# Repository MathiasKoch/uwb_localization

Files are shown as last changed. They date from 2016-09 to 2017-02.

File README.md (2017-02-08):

# Ultrawide band based localization system

First off, a comprehensive wiki on this sytem can be found at: [RSE-WIKI - 3D localization](http://rsewiki.elektro.dtu.dk/index.php/3D_localization)

The entire system is build to be easily ported to new hardware platforms, with minimum configuration.

The general folder structure is describe below, with the important hardware specific files highlighted and described.

| Folder | Contains |
| --- | --- |
| Drivers/ | Peripheral libraries, IMU drivers, DWM drivers, etc. |
| Inc/ | Include files (.h) |
| Inc/$(CPU)/ | Processor/device specific include files |
| Inc/hal.h | Hardware abstraction configuration file (Add new devices here first) |
| Linkers/ | Linker files for GCC (Processor specific) |
| MATLAB/ | MATLAB simulation scripts and design files |
| Middlewares/ | Middleware libraries (eg. USB middlewares) |
| PCB/ | DipTrace files for the PCB design |
| Related papers/ | Papers I have found relevant for the project |
| Scripts/ | Various helper scripts (eg. Python scripts for DFU management) |
| Src/ | All of the source files (.c/.cpp) |
| Src/$(CPU)/ | Processor/device specific source files |
| Src/periph/ | Peripheral setup source files (i2c, spi, tim, dma, etc.) |

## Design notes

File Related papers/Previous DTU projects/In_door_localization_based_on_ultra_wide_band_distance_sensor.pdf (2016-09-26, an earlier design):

## In-door Localization based on Ultra Wide Band Distance Sensor

Mathias Koch, s123950
Nicolai Sahl-Tjørnholm, s123860

DTU, 11. December 2015

Mathias Koch | Nicolai Sahl-Tjørnholm

## Abstract

To navigate an autonomous robot safely in its surroundings, the position of it must be known to some extent. One way of doing this is by having an external system capable of tracking the device of interest.
In this report a robust positioning system is introduced and tested. It consists of four anchors and one tag, and the position of the tag is estimated by trilateration of the distances from anchors to the tag. The final system is using a non-linear least squares algorithm to perform the trilateration.
Different test scenarios are set up and the results are compared. Tracking of a moving tag was showing very precise estimations, but with the same errors for every repetition of the same test. Tests with a non-moving tag showed estimation errors of ±5 cm.

## Contents

1 Introduction | 3
2 System Overview | 4
3 Position Estimation | 5
4 Results | 9
5 Conclusion | 13
6 Future Works | 13
7 References | 14
8 Appendix | 15

## 1 Introduction

To navigate a device through an environment it is crucial to know its position compared to the surroundings. It does not become less important when dealing with autonomous devices like a driving robot or an autonomous drone. To deal with this problem, a variety of sensors can be placed on-board the devices, to estimate its current position compared to its starting position, by for instance sensing acceleration in different directions. The problem with these techniques is that there will always occur some sort of drift in the measurements, meaning that as time goes on the error in the estimated position will increase. To correct this drifting of measurements, a system that estimates the device position based on distances to other devices, placed in the surroundings, can be used. These estimates can be fused with on-board sensors, to combine the best of both worlds.

Today the most commonly used and well known system of this type, is the Global Positioning System (GPS). It computes distances between satellites with known positions, to a GPS-device on earth and by utilizing geometry, it estimates the position of the GPS-device. This method has some quite unfortunate disadvantages such as low accuracy and extremely poor performance when used indoors. When it comes to navigation of robots, it is often required to have a high accuracy and it should be able to be used indoors.

Alternatives that are actually made for indoor positioning purposes is local positioning systems. These types of systems work somewhat like the GPS. Distances from anchors with known positions, are measured to a tag and a relative position is estimated. The way the distances are measured in these systems are by either by loss in signal strength or delay from transmission time till reception of a signal. The signal strength method is enough to estimate which room a device is in, but not much more than that. The signal delay method is more precise, but it is influenced by noise sources that uses the same RF bands as the transmitted signals. To overcome this issue, devices with Ultra Wide Band (UWB) transceivers has been developed. It is this technology that is explained throughout this report and used to obtain a high precision positioning system.

## 2 System Overview

The system consists of several devices that communicates and performs distance measurements to each other with UWB transceivers. The transceivers used are DW1000, a low power, single chip CMOS radio transceiver IC produced by decaWave. They span 6 RF bands from 3.5 GHz to 6.5 GHz and support data rates of 110 kbps, 850 kbps and 6.8 Mbps[1]. Due to the wide span on the RF bands, the performance of the transceivers are not affected by noise, in the same way a narrow banded system would be. This is due to the interferences often coming from narrow banded systems, like bluetooth or WiFi, thus having lower impact on a wide banded system. The manufacturer states that the operating range of the system may vary from 60 m line-of-sight (LOS) at 6.8 Mbps data rate to 250 m at the 110 kbps data rate and the accuracy is stated to be +/- 10 cm.
For this report a setup was made from four anchor nodes and one tag. It is possible, and recommended, to expand the system so that it consists of more anchors, since this will result in higher precision tracking and be more fault tolerant.

### 2.1 Distance measurements

In order to do distance estimation, a ranging algorithm based on time of flight is being used. This means that every communication package between nodes are precisely timestamped at time of transmission and again at time of reception, in order to calculate the propagation time. As the speed of light is constant, the distance between the transmitter and the receiver can be calculated as a direct scalar of the propagation time. In theory this alone should give a very accurate distance measurement, but this is not the case in reality. This is due to the fact that there is a lot of different delays in both the transmitting unit and the receiving unit, delays that are not always constant. The delays could depend on things like package size, processor type, electronics layout, transmission data rate and so forth. Furthermore the clocks of the two nodes has to be synchronized to perfection in order to have comparable timestamps, which is not possible as the crystals has some drift.

The solution to some of these issues, is to use what is called a two-way ranging scheme, allowing the system to compensate for some of the drift in the clock synchronization and some of the variable delays in the system. In a basic single-sided two-way ranging scheme you measure the time it takes for a message to propagate from device A to device B and reverse, subtracting the processing time on device B and dividing by two to get the average propagation time. In this case, an extension of the normal single-sided two-way ranging scheme is used called Double-sided Two-way ranging. The extension of the basic single-sided two-way ranging, means that instead of measuring the propagation time from one node to the other and back again, the process is repeated in reverse, meaning that the round-trip of device A to device B and back again is measured, and the round-trip time of device B to device A and back again is also measured. This makes it possible to compensate, in case of any difference in the processing time, internal delays etc. between the two devices. The process can be optimized, by using the reply from the first round-trip, as an initiator for the second round-trip, as seen in figure 1. It is however worth noting that even though this ranging scheme allows a good range estimate in just three packages, the last package ends up at the opposite device, of who initiated the

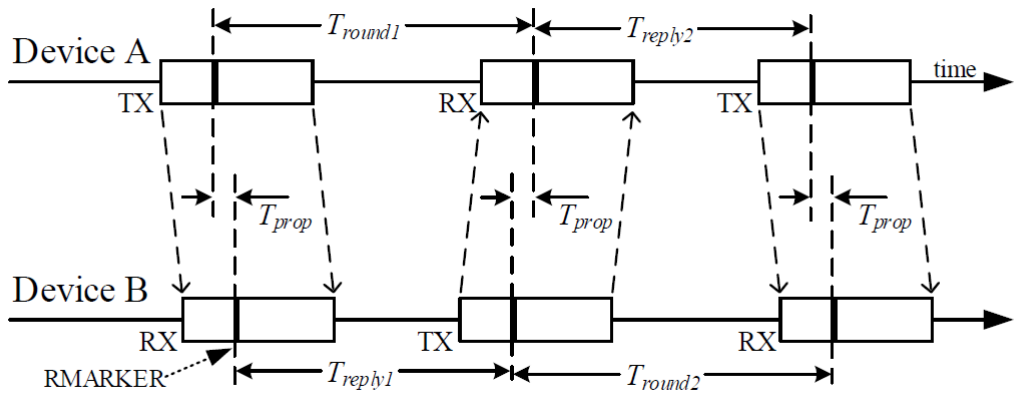
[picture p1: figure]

Figur 1: Double-sided Two-way ranging, using the reply of the first round-trip as initiator for the second round-trip.

ranging. This means that a fourth package is required to report the last Tround2 back to the initiator for distance calculation.

The resultant time-of-flight estimate Tprop can now be calculated as

Tˆ
prop =

Tround1Tround2 − Treply1Treply2

Tround1 + Tround2 + Treply1 + Treply2

(1)

And the distance can be calculated as

ri = TpropC | (2)

Where C is the speed of light, 3 · 10⁸ m/s.

## 3 Position Estimation

The problem of estimating the position of an object with unknown position, based on distance measurements between the object and multiple reference points, with known positions, are known as trilateration [2]. In theory trilateration is as simple, as solving a system of equations in the form of
(pi − p0)

T
(pi − p0) = r

2
i

(3)

where p0 denotes the position estimate of the object, pi the known position of the i’th reference point and ri the measured distance between the object and the i’th reference point. When structuring the trilateration problem in this way, equation (3) is equivalent to the equation of a sphere, with center point in pi and radius of ri
. The solution to a system like this, is essentially equivalent to finding the intersection point of the N spheres contained in the system, this intersection point will be the unknown position, p0.

This can be solved in a number of ways, ranging in complexity from simple hyperbolic interpolation and least squared methods to Extended Kalman filters and Particle filters. In this report we have chosen to focus on the least squares methods.

### 3.1 Linear Least Squares

The problem of estimating a position in 3 dimensions, from N distance measurements to known positions, can be solved as a least squares optimization problem. To do this the problem can be simplified into a linear system of N equations with 3 unknown variables in the form Ax = b, with

A =

P2,x − P1,x | P2,y − P1,y | P2,z − P1,z
P3,x − P1,x | P3,y − P1,y | P3,z − P1,z
Pn,x − P1,x | Pn,y − P1,y | Pn,z − P1,z

, x =

P0,x − P1,x

P0,y − P1,y

P0,z − P1,z

- , b =

b21

b31

bn1

(4)

where

(P0,x −P1,x)(Pn,x −P1,x) + (P0,y −P1,y)(Pn,y −P1,y) + (P0,z −P1,z)(Pn,z −P1,z) = bn1 (5)

1
2

[r

2
1 − r

2
n + d

2
n1

] = bn1

and dij being the distance between the i’th and the j’th node, given as

dij =

q
(Pi,x − Pj,x)

2 + (Pi,y − Pj,y)

2 + (Pi,z − Pj,z)

2 | (6)

The full derivation of these equation can be found in Appendix A.
With this given, a new problem arises, as the distance measurements contains noise and is therefore only distance approximations with some uncertainty. This is where the least squares approximation comes into play, as this uncertainty essentially means, that we are searching for a solution x, such that Ax ≈ b. By minimizing the sum of the squares of the residuals,

S = r

T
r = (b − Ax)

T
(b − Ax), | (7)

the following equation can be obtained [3]

AT Ax = ATb | (8)

From here, there are several possible methods to solve this equation, based on how AT A is conditioned. In this report we will only investigate the case where AT A is non-singular and well-conditioned, leading to the simple solution given in equation (9).

x = (AT A)

−1ATb | (9)

Now the position estimate of the robot p0, can be found as

p0 = x + p1 | (10)

In the cases where AT A is either singular or poorly conditioned, there is as mentioned before, still ways to solve the linear system of equations. These involves either normalized orthogonal decomposition or singular value decomposition. These cases will however not be investigated in this report, as the results of the best case, where AT A is non-singular and well-conditioned deemed unsatisfactory and neither of the two extended methods will increase the accuracy. The unsatisfactory solution, is due to the nonlinear nature of equation (3) and the errors existing in both the fixed reference positions, pi and the measurements, ri

, making it impossible for the linear least squares method to approximate the position with higher accuracy.

### 3.2 Nonlinear Least Squares

To overcome some of the issues with the linear least squares implementation, an algorithm based on a nonlinear least squares formulation is implemented instead. The efficient least squares trilateration algorithm [4]. The Efficient Least Squares Trilateration Algorithm for Mobile Robot Localization, used has the major advantage, that it is built solely on simple algebraic matrix instructions, meaning no matrix inversion is involved in the algorithm. This makes for an extremely robust algorithm, in the sense that it can handle singular matrices e.g. in the case of all anchors being positioned in the same single plane. Furthermore it means that the algorithm is extremely fast to process, which is an important factor, as the processing power might be very limited in real life applications.
Essentially the algorithm proposes a way to obtain the optimal position estimate of the robot, as an minimization problem in the form:

p0,opt = argmin
p0
S(p0) | (11)

Where
S(p0) = X

N

i=1

[(pi − p0)

T
(pi − p0) − r

2
]

2
(12)

With p0 denoting the estimated position of the robot, pi the position of the i’th reference point, N the number of reference points used and ri the measured distance between p0 and pi .

Using a least squares algorithm, we relieve ourselves from the constraint that is usually asso-ciated with equation systems with noise present, being that as soon as more equations are available than unknown variables, the system generally does not have one exact solution. This means that courtesy of using least squares approximations we are not limited to the case where N = 3, but this solution can be used in the general case where N ≥ 3, N ∈ N.

It has been chosen to include only the final equations required to calculate the position estimate in the report, the full derivation of said equations can be found in Appendix B.

The algorithm can be described in 7 steps:

1. Calculate a,B,c,f,f ’,H,H’,Q and U, from equations (13) - (20).
2. Calculate q

T q, from equation (21).

3. Calculate q3, from equation (24).
4. Calculate q1 and q2, from equation (25).
5. Calculate p0, from equation (26).
6. Choose one of the two candidates of p0.
7. Return p0.

a =

1
N

X

N

i=1

(pip

T
i pi − r

2
i pi), | a ∈ M3x1(R) | (13)

B =

1
N

X

N

i=1

[−2pip

T
i − (p

T
i pi)I + r

2
i
I] , | B ∈ M3x3(R) | (14)

c =

1
N

X

N

i=1

pi

, | c ∈ M3x1(R) | (15)

f = a + Bc + 2ccT
c , | f ∈ M3x1(R) | (16)

f

0 = [f1 − f3, f2 − f3]
T
, | f
| 0 ∈ M2x1(R) | (17)

H = −

2
N

X

N

i=1

pip

T

i + 2ccT
, | H ∈ M3x3(R) | (18)
H⁰ = [H1 − H3, | H2 − H3]
T
, | H⁰ ∈ M2x3(R) | (19)

The two matrices Q and U, can be obtained by orthogonal decomposition [5] of H’, with the result given by the relation
H⁰ = QU | (20)

Where Q is a 2x2 orthogonal matrix, and U is a 2x3 upper diagonal matrix.

q

T q =

1
N

X

N

i=1

(r

2
i − p

T
i pi) + c

T
c , | q
tq ∈ R | (21)

In the following, ukj references the element in the k’th row and the j’th column of U, vk references the k’th element of the vector QT
f

0 and qk references the k’th element of q. To make matters a little easier to read, we introduce 2 helping variables here given as

g1 =

u12v2

u11u22

−

v1

u11
(22)

g2 =

u12u23

u11u22

−

u13

u11
(23)

q3 can now be found as

q3 =

±1

g

2
2 +
u23

u22 2
+ 1
g1g2 +
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
u22 2
− g

2
1 + 2g1g2
v2

u22

u23

u22
(24)

− g

2/2
v2

u22 2
+ q

T qg

2
2 −
v2

u22 2
+ q

T q

u23

u22 2
+ q

T q

1/2

This will give rise to two solutions, due to the ±1, with only one of the two candidates resulting in the true p0. The true q can be chosen based on a number of criterion’s based on the application, e.g. it could be known that the true p0 is always on a specific side of the base plane, or that the current p0 cannot move far from the previous estimate of p0.

Now that we know the height of the p0 point, we can substitute into the two equations

q1 = g1 + g2q3 | q2 =
−

v2

u22

−

u23

u22
q3 | (25)

Lastly the estimated position can be obtained by

p0 = q + c | (26)

## 4 Results

During the project various techniques and methods have been tested, in order to achieve the best possible position estimate. This includes multiple time-of-flight range calculation schemes, different methods for solving the trilateration problem and eventually simple hardware alterations to reduce reflections.

Looking at just a single series of distance measurements, before processing the data will give the best overall assessment of what the system might be capable of, assuming the data is processed right. Such a measurement series can be seen in figure 2, together with the mean value of the series shown and ±3σ highlighted as a confidentiality interval. As it can be seen from the figure, nearly all of the measurements are within ±5 cm, way better than the specified ±10 cm from the manufacturer. These results are consistent across all of the tests conducted with non-moving nodes. The obtained precision is consistent with moving modes as well, as long as the nodes are in line of sight and does not come to close to the other tag, as they seem to require a minimum distance between each other of 10-15 cm.
With raw distance measurements within ±5 cm of each other, the system should be capable of delivering quite accurate three dimensional position estimates. There is however a couple of other things in play, when calculating position from distance measurements. First of all there is an overdetermined system of equations to be solved, as soon as more than three reference points are introduced and with the addition of measurement noise, these are generally prone to have no real solution. This means that the best position estimate obtainable is the position that makes for the least error, making it an optimization problem. This has been solved by the least squares method, leading to accurate position estimates in the cases where there is line of sight between the tag and all the anchors, there is no motion of any of the nodes and the nodes are oriented and positioned in a way that minimizes the reflection impact on the measurements.

Measurements of distance between two node laying still

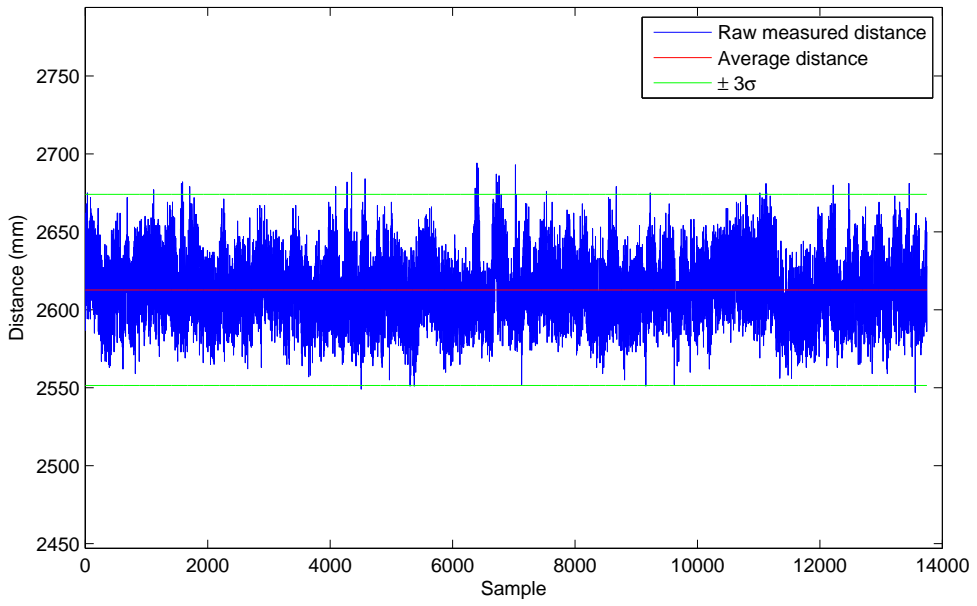
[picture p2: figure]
Sample; Distance (mm); Raw measured distance Average distance ± 3σ

Figur 2: Measurement series of distance between two nodes laying still.

In figure 3, the X and Y position of a small mobile robot, equipped with a tag and driving a preprogrammed route, can be seen before orienting and positioning the nodes to minimize reflection impact. It can be seen how the measurements are somewhat along the expected route, but with a lot of jitter, offset and unexplainable behaviour. As it turns out, this behaviour is explainable though, as it is cause by wrong distance measurements as a consequence of the reflections from walls containing higher power at reception than the direct route. This can be explained by looking at the antenna profile of the modules, as this antenna has so called dead-spots where the reception gains are extremely low. This means that in the case where the direct line of sight route hits a dead-spot and the reflections hits a non-dead-spot on the antenna, the reflections will seem like the superior signal to the system.

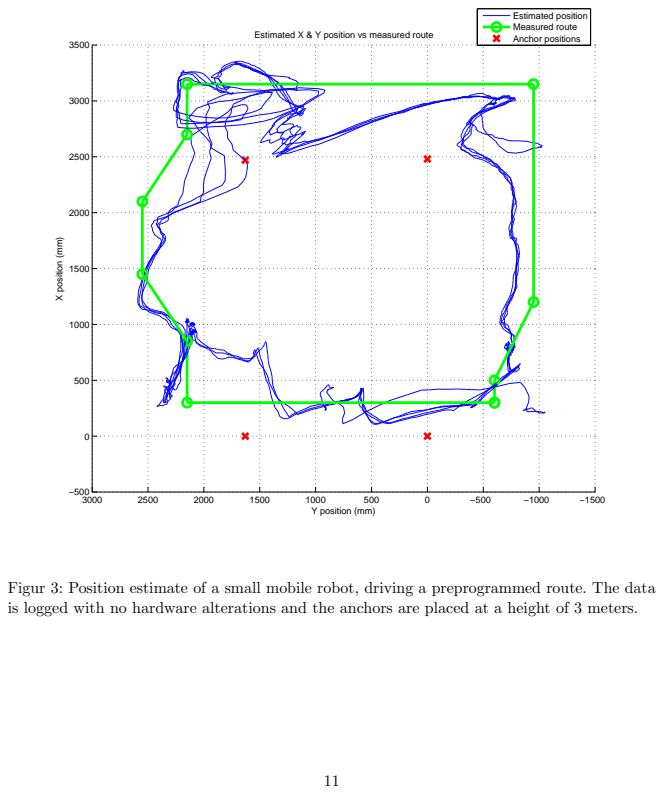
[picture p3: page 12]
Y position (mm); X position (mm); Estimated position Measured route Anchor positions

Estimated X & Y position vs measured route

Figur 3: Position estimate of a small mobile robot, driving a preprogrammed route. The data
is logged with no hardware alterations and the anchors are placed at a height of 3 meters.

By correcting for these antenna dead-spots as much as possible, it was possible to obtain much better results. In figure 4, the same small mobile robot, driving the same preprogrammed route can be seen, but this time the results are much better. The estimated route is still not the correct route, but there is a much better coherence between the estimated and true route.

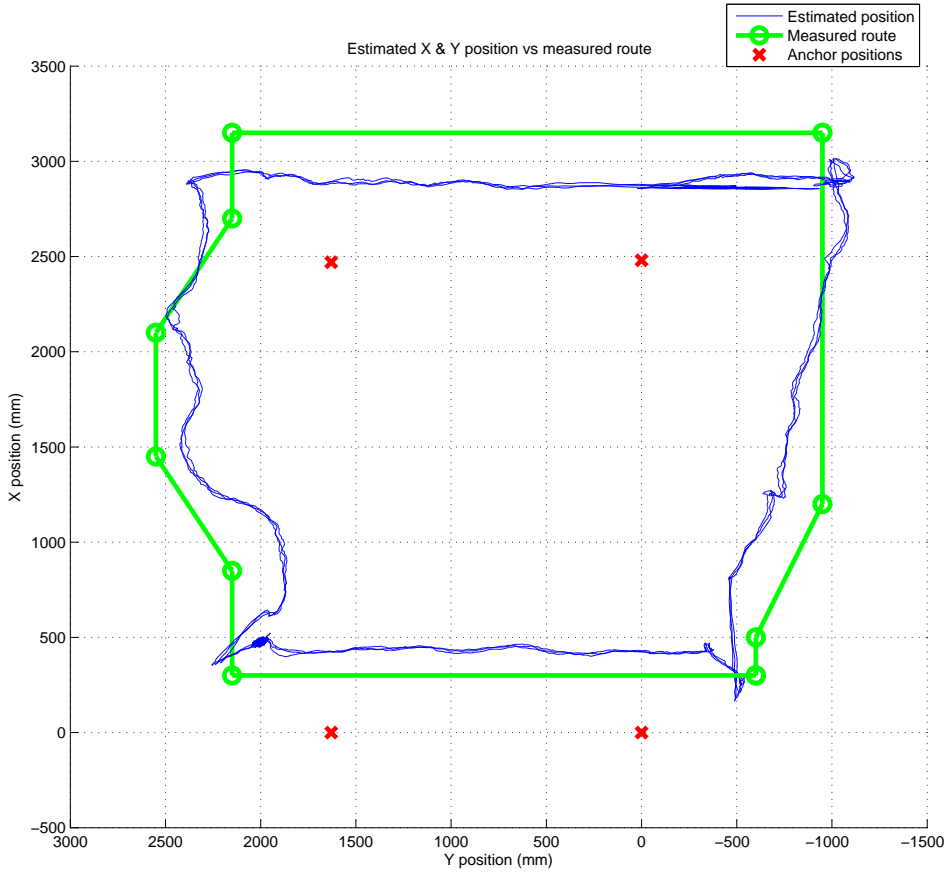
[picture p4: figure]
Y position (mm); X position (mm); Estimated position Measured route Anchor positions

Estimated X & Y position vs measured route

Figur 4: Position estimate of a small mobile robot, driving a preprogrammed route. The data is logged after doing hardware alterations to minimize reflections.

By looking at the distance measurement series individually, it can be seen how the system measures the exact same distances throughout the route, every round.

0 | 2000 | 4000 | 6000 | 8000 | 10000

1500

2000

2500

3000

3500

4000

4500

Anchor 1

Sample

Measured distance (mm)

0 | 2000 | 4000 | 6000 | 8000 | 10000

2200

2400

2600

2800

3000

3200

3400

3600

3800

Anchor 2

Sample

Measured distance (mm)

Raw measurements
FIR filtered
0 | 2000 | 4000 | 6000 | 8000 | 10000

2200

2400

2600

2800

3000

3200

3400

3600

3800

Anchor 3

Sample

Measured distance (mm)

0 | 2000 | 4000 | 6000 | 8000 | 10000

2000

2500

3000

3500

4000

4500

5000

Anchor 4

Sample

Measured distance (mm)

Figur 5: Distance measurements from each reference point to a small mobile robot, driving the preprogrammed route seen in figure 4. On the figure the raw distance measurements can be seen, as well as the signal after an FIR filter of 15 samples. The data is logged after doing hardware alterations to minimize reflections.

## 5 Conclusion

From the results of the performed tests of the system, it can be concluded that the system is capable of tracking an object with a tag mounted on it. The position estimate of the tag is within ±5 cm when the tag is not moved, which is twice as good as the promised ±10 cm by the manufacturer. When it comes to a moving object which is turning the antenna of the tag while moving around, the precision drops and the position error reaches approximately 20 cm. This is based on the calculated position compared to a hand-measured true position, thus not completely accurate.
The tests of the moving tag showed a very high precision during operation (positions were estimated with maximum ±5 cm differences between all rounds driven), but the accuracy was significantly lower when the tag was moving.

## 6 Future Works

As seen there are plenty of possibilities to improve on the system. This section will try to dive into some of the most obvious places to improve, expand and work with the system in the future.

One thing to improve on the current system, is to add a high sensitivity pressure sensor to each node, both the anchors and the tag. This should be added in order to obtain a relative pressure difference between each known position, the anchors, and the unknown tag position. With these N relative pressure differences it would be possible to calculate a relative height difference between each anchor and the tag, in order to estimate the height of the tag, even before measuring distances. In combination with a modified version of the implemented nonlinear least squares, this might lead to a better height estimation, leading to a better position estimate all together.

Another place to improve the current system, would be to alternate the current hardware of the anchors, in order to obtain a better antenna leading to less impact of reflections. Also the hardware needs to be able to charge the onboard battery through the usb port.

The last obvious place to expand the system, would be to implement the ability for the system to range in a mesh, meaning that all nodes obtains ranges to all other nodes in range. This would allow the system to auto obtain the fixed reference point positions and thus eliminate the need to measure the reference positions by hand.

## 7 References

[1] DecaWave. DW1000 User Manual. url: http://www.decawave.com/support/download/file/nojs/692. (http://www.decawave.com/support/download/file/nojs/692)
[2] F Thomas og L Ros. “Revisiting trilateration for robot localization”. und. I: Ieee Transa-ctions on Robotics, Ieee Trans. Robot, Ieee T Robo, Ieee T Robot, Ieee Trans Robot, Ieee Trans. Rob 21.1 (2005), s. 93–101. issn: 19410468, 15523098. doi: 10.1109/tro.2004. 833793. (http://dx.doi.org/10.1109/tro.2004.833793)
[3] William S. Murphy Jr. og Willy Hereman. “Determination of a position in three dimensions using trilateration and approximate distances”. I: (1999).
[4] Yu Zhou. “An Efficient Least-Squares Trilateration Algorithm for Mobile Robot Localization”. und. I: 2009 Ieee-rsj International Conference on Intelligent Robots and Systems (2009), s. 3474–3479.
[5] G.H. Golub og C.F. van Loan. Matrix computations. The Johns Hopkins University Press, 1996, 694 s. isbn: 0801854148, 9780801854149.

## 8 Appendix

Appendix A - Linear Least Squares Derivation

In a thee dimensional space, trilateration is equivalent to finding the intersection between N spheres of the form

(x − xi)

2 + (y − yi)

2 + (z − zi)

2 = r

2
i
(i = 1, 2, ..., N) | (27)

To linearize this equation, xj , yj and zj can be added and subtracted in (27), to give

(x − xj + xj − xi)

2 + (y − yj + yj − yi)

2 + (z − zj + zj − zi)

2 = r

2
i

(28)

By expanding (28) and regrouping the terms, leads to

(x − xj )(xi − xj ) + (y − yj )(yi − yj ) + (z − zj )(zi − zj )

=

1
2

[(x − xj )

2 + (y − yj )

2 + (z − zj )

2 − r

2
i + (xi − xj )

2 + (yi − yj )

2 + (zi − zj )

2
]

=

1
2

[r

2
j − r

2
i + d

2
ij ] = bij | (29)

With dij , being the distance between the i’th and the j’th node, given as

dij =

q
(xi − xj )

2 + (yi − yj )

2 + (zi − zj )

2 | (30)

By selecting the first reference point as the linearizing tool (j = 1), this leads to a linear system of (n − 1) equations in 3 unknowns of the form Ax = b, given as

(x − x1)(x2 − x1) + (y − y1)(y2 − y1) + (z − z1)(z2 − z1) = 1
2

[r

2
1 − r

2
2 + d

2
21] = b21 (31)
(x − x1)(x3 − x1) + (y − y1)(y3 − y1) + (z − z1)(z3 − z1) = 1
2

[r

2
1 − r

2
2 + d

2
31] = b31 (32)
. | (33)
(x − x1)(xn − x1) + (y − y1)(yn − y1) + (z − z1)(zn − z1) = 1
2

[r

2
1 − r

2
2 + d

2
n1

] = bn1 (34)

Where

A =

x2 − x1 | y2 − y1 | z2 − z1
x3 − x1 | y3 − y1 | z3 − z1
xn − x1 | yn − y1 | zn − z1

, x =

x − x1
y − y1
z − z1
- , b =

b21

b31

bn1

(35)

Appendix B - Nonlinear Least Squares Derivation

The problem is essentially the optimization problem given by

| p0opt = argmin · S(p0

(36)

where

S(p0 =

X

N

i=1

[(pi − p0

)

T
- (pi − p0

) − r

2
i

]

2
(37)

p0 denotes the estimate of the tag position , pi

the pre-mapped reference positions of the i’th anchor, ri the measured distance between p0 and pi and N is the number of reference points used to determine p0

Given pi and ri

, solving equation (36) is equivalent to solving

∂S(p0

)
∂p0

= a + Bp0 + [2p0p

T
0 + (p

T
0 p0

)I]c − p0p

T
0 p0 = 0 | (38)

where

a =

1
N

X

N

i=1

(pip

T
i pi − r

2
i pi
) | (39)

B =

1
N

X

N

i=1

[−2pip

T
i − (p

T
i pi

)I + r

2
i
I] | (40)

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
(41)

To simplify equation (38), we introduce a linear transform

p0 = q + c | (42)

and obtain an equation containing no quadratic term of q

(a + Bc + 2ccT

c) + {Bq + [2ccT + (c

T

c)I]q} − qqT q = 0 | (43)

Defining

f = a + Bc + 2ccT
c | (44)
D = B + 2ccT + (c

T
c)I | (45)

we rewrite equation (43) as

f + [D - (qT
q) I]q = 0 | (46)

It is noticed that

D - (qT
q) I = −

2
N

X

N

i=1

pip

T

i + 2ccT
(47)

which is an n × n symmetric matrix and does not contain q. By defining

H = D-(qT
q)I | (48)

we obtain from equation (46)
F = Hq = 0 | (49)

This equation is a linear system of n equations of the unknown n-dimensional vector q. If H is full rank, q can be calculated as q = -H⁻¹
f.
In case H is not full rank, which would be the case if all anchors were placed in the same height, equation (49) does not represent a system of n independent linear equations and we cannot uniquely determine q from equation (49).
To make a solution for the cases where H is not full rank, we first denote the k’th component of f as fk and the k’th row of H as h

T
k

. We construct a n-1 dimensional vector

f = [f1⁻ fn, ..., fn−1⁻ fn]

T
(50)

and a (n − 1) × n matrix

H⁰ = [h1 − hn, ..., hn−1 − hn]
T
(51)

We can then obtain from equation (49)

f

0 + H⁰q = 0 | (52)

Then by using orthogonal decomposition [5], we obtain

H⁰ = QU | (53)

where Q is a (n − 1) × (n − 1) orthogonal matrix and U is a (n − 1) × n upper diagonal matrix. By multiplying both sides of equation 52 by QT
, we get

QT
f
0 + Uq = 0 | (54)

Rewriting equation (54) in its scalar form, we have for the 3D case
(
v1 + u11q1 + u12q2 + u13q3 = 0 v2 + u22q2 + u23q3 = 0

(55)

where vk denotes the k’th component of QT f

0
, ukj the (k, j) entry of U and qk the k’th component of q. From equation (55) we obtain

q1 = ( u12v2

u11u22

−

v1

u11

) + ( u12u23
u11u22

−

u13

u11

)q3

q2 = −

v2

u22

−

u23

u22

q3

(56)

Now we have 3 unknowns but 2 equations, and therefore need one more independent equation to solve for q. One valid constraint is

q

2
1 + q

2
2 + q

2
3 = q
T q | (57)

where q

T q can be obtained from D − q

T q = H as

q

T q = −

1
N

X

N

i=1

p

T
i pi +

1
N

X

N

i=1

r

2
i + c

T
c | (58)

substituting equation (56) into (57), we obtain

[( u12v2

u11u22

−

v1

u11

) + (u12u23

u11u22

−

u13

u11

)q3]

2 + [ v2

u22

+

u23

u22

q3]

2 + q

2
3 = q
T q | (59)

which is a quadratic equation of q3 and can be solved in closed form. Substituting the resulting q3 into equation (56), we can obtain q1 and q2.

Appendix C - Hardware Schematic

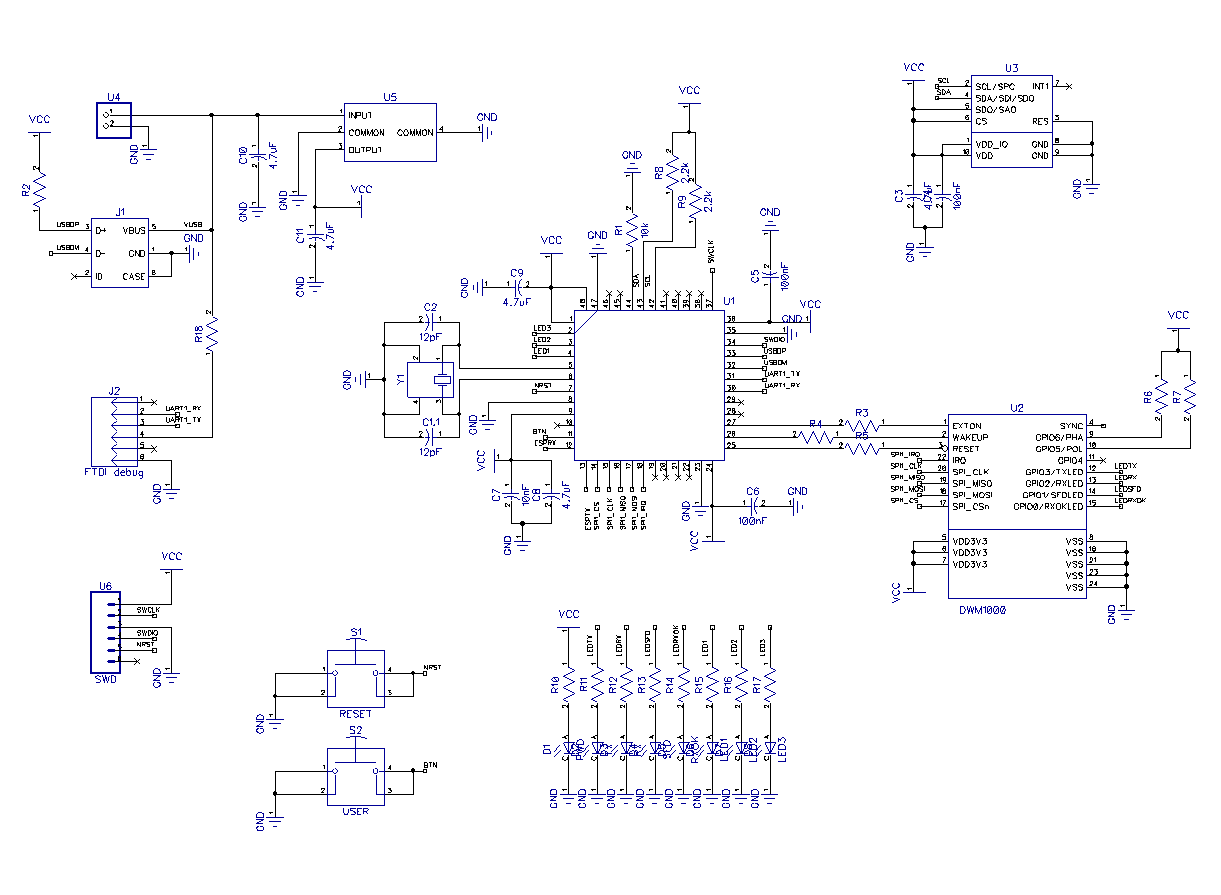
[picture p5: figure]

Figur 6: Schematics of the hardware.

Appendix D | - MATLAB Scripts
Appendix D.1 | Script
1 | c l e a r a l l
2 | c l o s e a l l

3

4

5 | l o g . anch o r s = [ 0 | 0 | 2960 | % Anchor 1
6 | 2480 | 0 | 2960 | % Anchor 2
7 | 2470 | 1630 2960 | % Anchor 3
8 | 0 | 1630 2 9 6 0 ] ’ ; | % Anchor 4 | % [mm]

9

10
11 | l o g . r e f = | [ 0 | 0 | 0 | % Poin t 1
12 | | 200 | 0 | 0 | % P oin t 2
13 | 900 | −350 0 | % P oin t 3
14 | 2850 | −350 0
15 | 2850 | 2750 0
16 | 2400 | 2750 0
17 | 1800 | 3150 0
18 | 1150 | 3150 0
19 | 550 | 2750 0 ] ’ ;

20
21 l o g . r e f = [ ] ;

22
23 l o g .AVG = 1 5;

24

25
26 | d e l e t e ( i n s t r f i n d a l l ) ;
27 | s = s e r i a l ( ’ /dev/ttyUSB0 ’ ) ;
28 | s e t (s , ’ BaudRate ’ , 1 1 5 2 0 0 ) ;
29 | s e t (s , ’ Da taBi ts ’ , 8 ) ;
30 | s e t (s , ’ S t o pBi t s ’ , 1 ) ;
31 | f open ( s ) ;
32 | s . ReadAsyncMode = ’ c o n ti n u o u s ’ ;
33 | re ad a s ync ( s ) ;
34 | w hil e ( s . B y t e sA v ail a bl e <= 0 )
35 | %
36 | end

37
38 | l o g . time = [ ] ;
39 | l o g . mean = [ ] ;
40 | l o g . x y z nl = [ ] ;
41 | l o g . x y z l = [ ] ;
42 | l o g . el a p s e d = [ ] ;
43 | i = 1 ;
44 | i n i t = 0 ;
45 | e s c a p e = 1 ;
46 | w hil e ( e s c a p e == 1 )
47 | s S e ri al D a t a = f s c a n f ( s ) ;
48 | f l u s h i n p u t ( s ) ;
49 | t = s t r s p l i t ( s S e ri alD a t a , ’ \ t ’ ) ;
50 | anc = s t r s p l i t ( t {1} , ’ : ’ ) ;

51 | i f anc {1} == ’N’
52 | N = s t r 2 d o u bl e ( anc ( 2 ) ) ;
53 | i f s i z e (t , 2 )−1 == N
54 | i f i n i t == 0
55 | Fs = 0. 0 1∗N;

56
57 | % Raw measurements pl o t
58 | f i g u r e ( ’Name ’ , ’RAW’ , ’ u ni t s ’ , ’ n o rm aliz e d ’ , ’
| | o u t e r p o s i t i o n ’ , [ 0 0. 5 0. 5 0 . 5 ] , ’ KeyPressFcn ’ , ’
| | e s c a p e = 0 ; ’ )
59 | h old on
60 | f o r n = 1 :N
61 | | h(n) = pl o t ( 0 ) ;
62 | | mn(n) = pl o t ( 0 , ’ r ’ ) ;
63 | end
64 | y l a b e l ( ’ Di s t a n c e (mm) ’ )
65 | x l a b e l ( ’Time ( s ) ’ )

66
67 | % XYZ s u b pl o t s
68 | f i g u r e ( ’Name ’ , ’XYZ’ , ’ u ni t s ’ , ’ n o rm ali z e d ’ , ’
| | o u t e r p o s i t i o n ’ , [ 0 0 0. 5 0 . 5 ] , ’ KeyPressFcn ’ , ’
| | e s c a p e = 0 ; ’ )
69 | s u b pl o t ( 3 , 1 , 1 )
70 | xp = pl o t ( 0 ) ;
71 | y l a b e l ( ’X’ )
72 | s u b pl o t ( 3 , 1 , 2 )
73 | yp = pl o t ( 0 ) ;
74 | y l a b e l ( ’Y’ )
75 | s u b pl o t ( 3 , 1 , 3 )
76 | zp = pl o t ( 0 ) ;
77 | y l a b e l ( ’Z ’ )
78 | x l a b e l ( ’Time ( s ) ’ )

79

80
81 | % XY pl o t
82 | f i g u r e ( ’Name ’ , ’XY’ , ’ u ni t s ’ , ’ n o rm ali z e d ’ , ’
| | o u t e r p o s i t i o n ’ , [ 0 . 5 0 0. 5 1 ] , ’ KeyPressFcn ’ , ’
| | e s c a p e = 0 ; ’ )
83 | h old on
84 | %xlim ([ −1500 4 0 0 0] )
85 | %ylim ([ −1500 4 0 0 0] )
86 | y l a b e l ( ’Y (mm) ’ )
87 | x l a b e l ( ’X (mm) ’ )

88
89 | %f o r n = 1 :max ( [ s i z e ( l o g . r e f , 1 ) N] )
90 | % | i f n<=N

91 | % | pl o t ( l o g . anch o r s ( 1 , n) , l o g . anch o r s ( 2 , n) , ’ rx
| | ’ , ’ LineWidth ’ , 2 , ’ MarkerSize ’ , 1 0 ) ;
92 | %
93 | % | end
94 | % | i f n<=s i z e ( l o g . r e f , 1 )
95 | % | pl o t ( l o g . r e f ( 1 , n) , l o g . r e f ( 2 , n) , ’ gx ’ , ’
| | LineWidth ’ , 2 , ’ MarkerSize ’ , 1 0 ) ;
96 | % | end
97 | %end
98 | xy = pl o t 3 ( 0 , 0 , 0 ) ;
99 | d a s p e c t ( [ 1 1 1 ] ) ;
100 | %l e g e n d ( ’ Anchors ’ , ’ R e f e r e n c e s ’ )

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

104
105 | i n i t = 1 ;
106 | end

107
108 | t s t a r t = t i c ;
109 | l o g . time = [ l o g . time i ∗Fs ] ;

110
111 | f o r n = 1 :N
112 | l o g . raw ( i , n) = s t r 2 d o u bl e ( t (n+1) ) ;
113 | s e t (h(n) , ’XData ’ , l o g . time ( 1 : i ) , ’YData ’ , l o g . raw ( : , n)
) ;
114 | end
115 | ax = g e t (h ( 1 ) , ’ Parent ’ ) ;
116 | s e t ( ax , ’XLim ’ , [ ( i −400)∗Fs ( i +100)∗Fs ] ) ;

117

118
119 | i f ( i > l o g .AVG+1)
120 | mean val = sum( l o g . raw ( i −(l o g .AVG−1) : i , : ) ) / l o g .AVG;
121 | l o g . mean = [ l o g . mean ; mean val ] ;
122 | f o r n = 1 :N
123 | | s e t (mn(n) , ’XData ’ , l o g . time ( 1 : i ) , ’YData ’ , l o g .
| | mean ( : , n) ’ ) ;
124 | end

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

128

129
130 | l o g . x y z nl = [ l o g . x y z nl P0 ] ;

131 | l o g . x y z l = [ l o g . x y z l P 0 l ] ;

132
133 | s e t ( xy , ’XData ’ , l o g . x y z nl ( 1 , : ) , ’YData ’ , l o g . x y z nl
( 2 , : ) , ’ZData ’ , l o g . x y z nl ( 3 , : ) ) ;

134
135 | s e t ( xp , ’XData ’ , l o g . time ( l o g .AVG+2: i ) , ’YData ’ , l o g .
x y z nl ( 1 , : ) ) ;
136 | s e t ( yp , ’XData ’ , l o g . time ( l o g .AVG+2: i ) , ’YData ’ , l o g .
x y z nl ( 2 , : ) ) ;
137 | s e t ( zp , ’XData ’ , l o g . time ( l o g .AVG+2: i ) , ’YData ’ , l o g .
x y z nl ( 3 , : ) ) ;

138
139 | drawnow
140 | e l s e
141 | l o g . mean = [ l o g . mean ; l o g . raw ( i , : ) ] ;
142 | end

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

13

14 | f o r n = 1: 2
15 | f m (n) = f (n)−f ( 3 ) ;
16 | end
17 | f m = t r a n s p o s e (f m ) ;

18

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

27

28
29 | g1 = ( n l s t r u c t .U( 1 , 2 ) ∗v ( 2 ) ) / ( n l s t r u c t .U( 1 , 1 ) ∗ n l s t r u c t .U( 2 , 2 )
| ) − v ( 1 ) / n l s t r u c t .U( 1 , 1 ) ;

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

32
33 | g31 = v ( 2 ) / n l s t r u c t .U( 2 , 2 ) ;

34
35 | g32 = n l s t r u c t .U( 2 , 3 ) / n l s t r u c t .U( 2 , 2 ) ;

36
37 | q ( 3 , 1 ) = −(g1∗g2 + g31 ∗ g32 + (− g1 ˆ2∗ g32 ˆ2 − g1 ˆ2 + 2∗ g1∗g2∗g31
| ∗g32 − g2 ˆ2∗ g31 ˆ2 + qtq ∗g2 ˆ2 − g31 ˆ2 + qtq ∗g32 ˆ2 + qtq )
| ˆ ( 1 / 2 ) ) / ( g2 ˆ2 + g32 ˆ2 + 1 ) ;
38 | q ( 3 , 2 ) = −q ( 3 , 1 ) ;

39
40 | q ( 1 , 1 ) = g1+g2∗q ( 3 , 1 ) ;
41 | q ( 1 , 2 ) = g1+g2∗q ( 3 , 2 ) ;

42
43 | q ( 2 , 1 ) = −g31−g32 ∗q ( 3 , 1 ) ;
44 | q ( 2 , 2 ) = −g31−g32 ∗q ( 3 , 2 ) ;

45
46 | qo = z e r o s ( 2 , 3 ) ;

47
48 | qo ( 1 , : ) = q ( : , 1 ) + n l s t r u c t . c ;
49 | qo ( 2 , : ) = q ( : , 2 ) + n l s t r u c t . c ;

50
51 | xyz = qo ( 1 , : ) ;
52 | end

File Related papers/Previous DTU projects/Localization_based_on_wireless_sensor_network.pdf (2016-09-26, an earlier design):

## Localization based on wireless sensor network

Mathias Jenning Koch
s123950
22. January 2016

Abstract - It is required for any autonomous or semi-autonomous robot, that the robot knows its own location in order to navigate and maneuver safely. This is the case for ground based robots as well as airborne robots, but in the case of airborne robots like unmanned aerial vehicles (UAV) the need to know location expands from two dimensions to three dimensions because of the altitude level. This project investigates a few ways to improve on a previously developed system for localization in three dimensions. It is investigated whether high precision pressure sensors can improve the accuracy of the estimated position by difference of pressure. A solution allowing fixing the anchors flat on any surface without jeopardizing the result is also proposed.

Introduction

The main objective of this project, has been to determine whether a highly sensitive pressure sensor on each node of the localization system, could be used to increase the accuracy of the position estimate. This could be the case through a better height estimate courtesy of difference of pressure on the tags and anchors in the system. Furthermore it has been investigated whether a ground plane behind the antenna, would eliminate the need for each node to be 15 cm from all obstacles as described in the datasheet of the ranging modules in use [1].

Previous Work

The localization system used in this project has been developed during a previous project [2], where a basic three dimensional localization was shown as a proof-of-concept of the technology. The system consists of at least four anchors and a tag equipped with DWM1000 modules, allowing precise time of flight ranging, in order to do trilateration. This system did however turn out to come with some limitations, such as the need for all the nodes to be positioned at a minimum distance of 15 cm from all obstacles and a rather jumpy height estimate of the system, in the case where all the anchors are placed in the same Z-plane.

Implementation

For this project a new set of anchors and tags has been developed, with the addition of a battery charging circuit, a sensitive pressure sensor and a smaller Cortex-M0 processor for the anchors, allowing less power consumption as well as USB programming.

Pressure Sensor
To include a pressure sensor into the existing nonlinear least squares implementation of the system, the underlying set of equations must be expanded. It was chosen to test only the approach of using one extra equation, containing information of all the anchors pressure measurements combined and then compared with the pressure measurement of the tag. This approach was chosen mainly because it would lead to the smallest computational increase compared to no pressure compensation. The basic idea, is to calculate the altitude above sea level of all the pressure measurements by

ASL(p) = (1 −

p
1013.25

0.190263
) · 44330.8 [m]
(1)
This way it is possible to average the altitude above sea level of the fixed anchors, in order to find the difference between the actual height of the anchors and the height calculated from the pressure. The same procedure could be done for the tag, with the unknown being the actual height, for which it would be possible to solve. The equation to be included in the set of equations for the nonlinear least squares approximation would then be given as:

ALS(P0) − G

T A0 − ALS(Mp) + G

T
c = 0 (2)

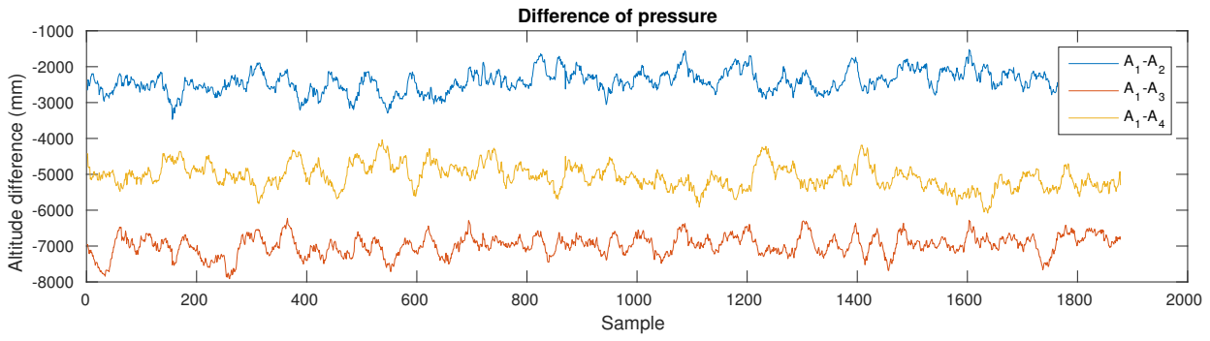
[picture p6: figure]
Sample; Altitude difference (mm); Difference of pressure

Figure 1: Difference of altitude calculated through the pressure of four anchors. Difference can be seen to vary around a meter, making the difference of pressure an nonviable method of getting a more accurate estimate.

with Mp being the mean of the pressure measurements from the anchors, P0 being the pressure measurement of the tag, A0 being the position of the tag, c being the average of the positions of the anchors and G = [0 0 1]T being a simple vector to select only the height part.
The pressure equation is weighted by a constant W, allowing to make the pressure weigh more or less than the distance measurements in the final position estimate. From the set of N+1 equations, it is then possible to calculate a performance index to minimize given by:

S(A0) = X

N

i=1

[(Ai − A0)

T
(Ai − A0) − r

2
i

]

2

+ W(ALS(P0) − G

T A0 − ALS(Mp) + G

T
c)
(3)

with ri being the distance measurement between the i’th anchor, Ai
, and the tag. This optimization problem can be solved in numerous ways. As stated already it has been chosen to solve it through a nonlinear least squares approximation in this case. Specifically the nonlinear least squares algorithm has been chosen to be the Levenberg-Marquardt algorithm, as this is able to solve the set of equations and it is fairly easy to implement in C at a later stage.

Ground Plane
In order to allow mounting the anchors of the system flat on eg. the ceiling or a wall, it was been investigated whether it would be possible to add a ground layer underneath the antenna to overcome the limitation of the DWM1000 modules of needed at least 15 cm to all obstacles when mounting. This limitation is in place in order to avoid as much variation in the reflected signals coming from behind the antenna as possible. To test the proposed solution, a test setup has been created, in where a tag is fixed at one end of a wood beam and two anchors, one with the proposed solution and one without, at the other end of the beam. A sketch of the combined setup can be seen in figure 2.

Figure 2: Test setup to evaluate the proposed shielding of background antenna noise.

With this test setup the properties of the system could be investigated in different situations, without the risk of changing the actual distance between the tag and anchors.

Results

The purpose of this project has been to investigate whether pressure sensors could be used to heighten the quality of the position estimate, as well as investigate ways of fixing anchor points flat on ceilings and walls without having disruptive reflections ruining the system.

Pressure Sensor
The pressure sensors turned out to contain way to much uncorrelated noise to use for this. The individual pressure sensors contains measurement noise equivalent to 10 − 20 cm, which in itself would not be devastating for this application. Unfortunately the sensor signals also contain a low

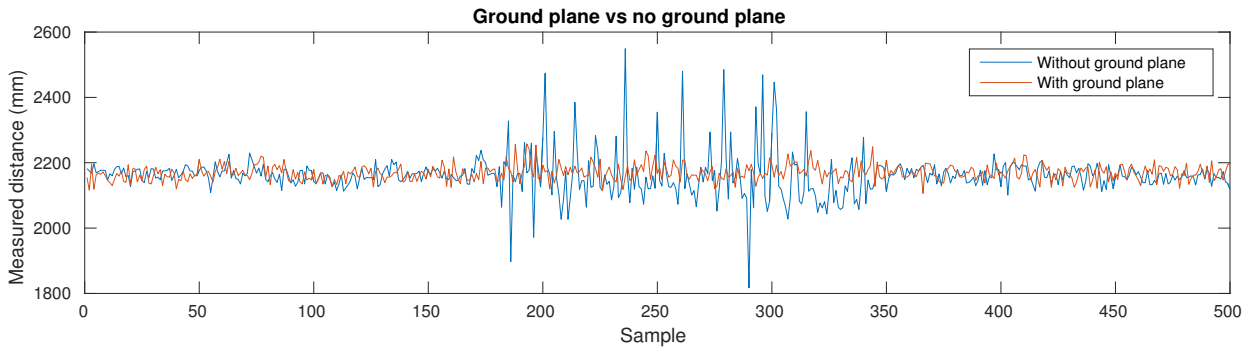
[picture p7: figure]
Sample; Measured distance (mm); Ground plane vs no ground plane; Without ground plane With ground plane

Figure 3: Distance measurements of two anchors, one with ground plane behind the antenna and one without. Both affected by the same disturbance behind the anchors.

frequency component that seems to wander ±50
cm, in a totally uncorrelated fashion if comparing multiple equivalent sensors. A simple difference comparison of the pressure sensors can be seen in figure 1, where the best case expected outcome should have been a constant difference between the sensors, meaning that even though the pressure of the room changes, the multiple sensors would be able to compensate. As it can be seen on figure 1 however, the difference between the sensors varies about one meter, meaning that the difference of pressures are useless in regards to obtaining a height estimate within the target of 10-20 cm.

Ground Plane

The proposed solution of extending the ground plane underneath the antenna of the anchors, in order to avoid disturbing reflections from behind, has proven much better results than the pressure sensor. The difference between an anchor with the ground plane fix applied and one without can be seen in figure 3. It can be seen how a disturbance in the form of waving a large metal sheet behind the antenna is affecting the two distance measurements. It can be seen on figure 3, how the disturbance is fully shielded by the

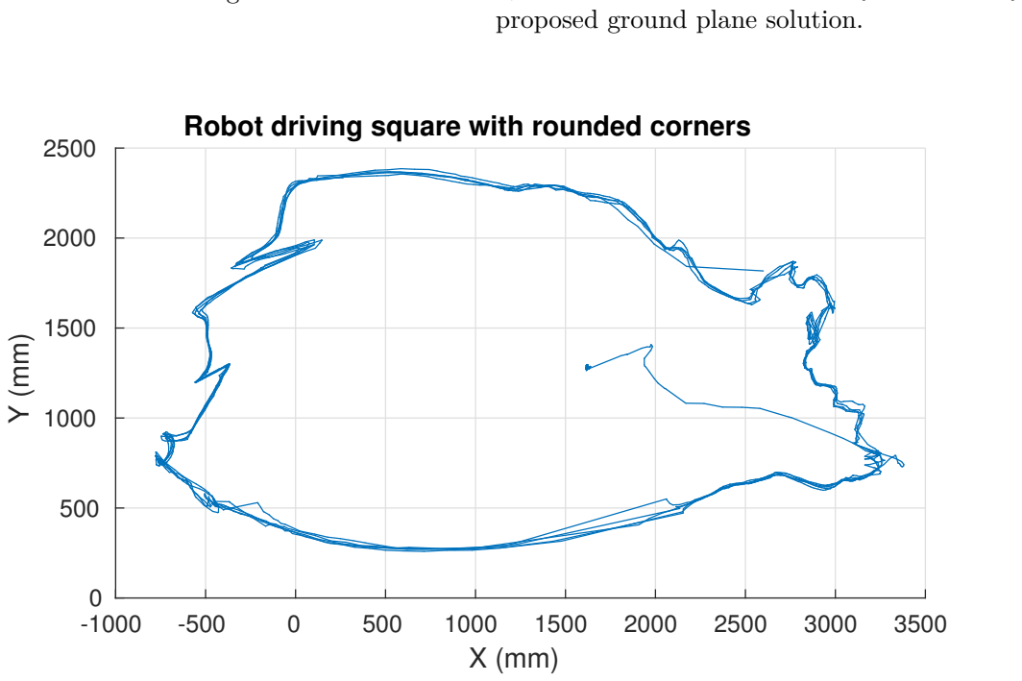
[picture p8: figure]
proposed ground plane solution.

Robot driving square with rounded corners

Figure 4: Position estimate of small robot driving square with rounded corners. Estimated position of each round can be observed as being very close to the other rounds, meaning measurements are very repeatable.

In figure 4, the combined system can be seen evaluated by a mobile robot driving along a line in the shape of a square with rounded corners. The results of the test is very similar to the tests performed previously with large metal sheets behind the anchors to shield from behind and also similar to the tests performed with the anchors positioned 20 cm from all obstacles [2].

The results are however still nothing like the actual square, one could wish for. The reasons for this and the potential solutions can be many and will have to be investigated further in future project work, for the system to reach its full potential.

Discussion

During this project it has been ruled out to use a pressure sensor to obtain a more accurate position estimate through sensor fusion. The only real advantage of having the pressure measurements available with regards to estimating position in three dimensions, would be to rule out potential dualities in the solution of the nonlinear least squares estimate. It has however been decided, that this small advantage is not worth the extra cost and complexity added by the pressure sensor.

Conclusion

All the tests evaluated on the system has proven, that the distance measurements and thus the position estimate has an extremely high repeatability, which means that even though the position estimate is not always equal to the actual absolute position of the tag, the estimated position always evaluates to the same estimate under the same conditions. This leads me to conclude that the error in the estimated positions are not caused by noise in the distance measurements and that it thus might be possible to calibrate the system to compensate for the error.

Future Work

Working on with the system there is enough to work on, including finding the actual cause of the wrong position estimates as the main priority, introducing mesh-ranging into the system to allow all nodes in the system to range with each other, and not just tag to anchor. This would also eliminate the need for measuring the position of the anchors by hand. Furthermore it would be interesting to use either an ultrasonic sensor or an infrared sensor to obtain a precise height measurement instead of the proposed pressure solution. It would also be interesting to fuse the output estimate of this system with an IMU and the actuator inputs in a Kalman filter to obtain a truly accurate position of a drone.

References

[1] DecaWave. DW1000 User Manual. url: http: / / www . decawave . com / support / download / file/nojs/692.
[2] Mathias Koch and Nicolai Sahl-Tjørnholm. “In-door Localization based on Ultra Wide Band Distance Sensor”. In: (2015).

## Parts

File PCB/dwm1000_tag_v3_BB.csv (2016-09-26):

RefDes | Name | Value | Quantity | Pattern
C1 | CAP_0805 | 4.7uF | 1 | CAP_0805
C2 | CAP_1210 | 47uF/1210 | 1 | CAP_1210
C3 | CAP_0603 | 27pF | 1 | CAP_0603
C4, C7, C8, C41, C42 | CAP_0603 | 100nF | 5 | CAP_0603
C5, C6 | CAP_0603 | 12pF | 2 | CAP_0603
C9, C40 | CAP_0603 | 10nF | 2 | CAP_0603
C10 | CAP_0603 | 1uF | 1 | CAP_0603
C11, C12, C13 | CAP_0603 | 4.7uF | 3 | CAP_0603
C14, C15, C16, C17, C18, C19, C20 | CAP_0603 | 10uF | 7 | CAP_0603
D1 | LEDCHIP-LED0603 | PWR | 1 | CHIP-LED0603
D2 | LEDCHIP-LED0603 | TX | 1 | CHIP-LED0603
D3 | LEDCHIP-LED0603 | RX | 1 | CHIP-LED0603
D4 | LEDCHIP-LED0603 | SFD | 1 | CHIP-LED0603
D5 | LEDCHIP-LED0603 | RXOK | 1 | CHIP-LED0603
D6 | LEDCHIP-LED0603 | LED1 | 1 | CHIP-LED0603
D7 | LEDCHIP-LED0603 | LED2 | 1 | CHIP-LED0603
D8 | SMBJ5.0A |  | 1 | DO-214AA
D9 | 1PS76SB10 |  | 1 | SOD-323
D10 | 1PS76SB10 | NM | 1 | SOD-323
J1 | ZX62-B-5P |  | 1 | ZX62R-B-5P
J2, J3 | 1-644456-0 |  | 2 | HDR-1x10T/2.54/25x2
L1 | SRN3015-220M | 22uH | 1 | 3.0mm x 3.0mm
Q1 | DMG2305UX |  | 1 | SOT23
R1, R8 | RES_0603 | 10k | 2 | RES_0603
R2 | RES_0603 | 47k | 1 | RES_0603
R3 | RES_0603 | 12k4 | 1 | RES_0603
R4 | RES_0603 | 91k | 1 | RES_0603
R5, R6 | RES_0603 | 100k | 2 | RES_0603
R7, R9 | RES_0603 | 22R | 2 | RES_0603
R10, R11, R12, R13, R14, R15, R16 | RES_0603 |  | 7 | RES_0603
R19 | RES_0603 | 1k5 | 1 | RES_0603
R20, R21 | RES_0603 | 2.2k | 2 | RES_0603
S1 | MC32882 | RESET | 1 | KMR221G LFS
S2 | MC32882 | USER | 1 | KMR221G LFS
U1 | DWM1000 |  | 1 | DWM1000
U2 | STM32F302CCT6 |  | 1 | LQFP48/7x7
U3 | BCM857BS |  | 1 | SOT363
U4 | ISL85410 |  | 1 | L12.4x3
U9 | MPU9250 |  | 1 | QFN-24/3x3x1
Y1 | CFPX-5 |  | 1 | CFPX-5

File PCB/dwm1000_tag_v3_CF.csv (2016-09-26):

RefDes | Name | Value | Quantity | Pattern
C1 | CAP_0805 | 4.7uF | 1 | CAP_0805
C3 | CAP_0603 | 27pF | 1 | CAP_0603
C4, C7, C8, C41, C42 | CAP_0603 | 100nF | 5 | CAP_0603
C5, C6 | CAP_0603 | 12pF | 2 | CAP_0603
C9, C40 | CAP_0603 | 10nF | 2 | CAP_0603
C10 | CAP_0603 | 1uF | 1 | CAP_0603
C11, C12, C13 | CAP_0603 | 4.7uF | 3 | CAP_0603
C14, C15, C16 | CAP_0603 | 10uF | 3 | CAP_0603
D1 | LEDCHIP-LED0603 | PWR | 1 | CHIP-LED0603
D2 | LEDCHIP-LED0603 | TX | 1 | CHIP-LED0603
D3 | LEDCHIP-LED0603 | RX | 1 | CHIP-LED0603
D4 | LEDCHIP-LED0603 | SFD | 1 | CHIP-LED0603
D5 | LEDCHIP-LED0603 | RXOK | 1 | CHIP-LED0603
D7 | LEDCHIP-LED0603 | LED2 | 1 | CHIP-LED0603
D9, D10 | 1PS76SB10 |  | 2 | SOD-323
J1 | ZX62-B-5P |  | 1 | ZX62R-B-5P
J2 | CrazyFlie_EXP_HEADER | Left | 1 | CrazyFlieHeader
J3 | CrazyFlie_EXP_HEADER | Right | 1 | CrazyFlieHeader
L1 | SRN3015-220M | 22uH | 1 | 3.0mm x 3.0mm
R3 | RES_0603 | 12k4 | 1 | RES_0603
R4 | RES_0603 | 91k | 1 | RES_0603
R5, R6 | RES_0603 | 100k | 2 | RES_0603
R7, R9 | RES_0603 | 22R | 2 | RES_0603
R8 | RES_0603 | 10k | 1 | RES_0603
R10, R11, R12, R13, R14, R16 | RES_0603 |  | 6 | RES_0603
R19 | RES_0603 | 1k5 | 1 | RES_0603
R20, R21 | RES_0603 | 2.2k | 2 | RES_0603
S1 | MC32882 | RESET | 1 | KMR221G LFS
S2 | MC32882 | USER | 1 | KMR221G LFS
U1 | DWM1000 |  | 1 | DWM1000
U2 | STM32F302CCT6 |  | 1 | LQFP48/7x7
U4 | ISL85410 |  | 1 | L12.4x3
U5 | DS28E05 |  | 1 | SOT23
U9 | MPU9250 |  | 1 | QFN-24/3x3x1
Y1 | CFPX-5 |  | 1 | CFPX-5

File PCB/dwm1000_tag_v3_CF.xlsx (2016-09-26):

RefDes | Name | Value | Quantity | Pattern | Mouser
D9, D10 | 1PS76SB10 |  | 2 | SOD-323 | http://www.mouser.dk/ProductDetail/NXP-Semiconductors/1PS76SB10115/
J1 | ZX62-B-5P |  | 1 | ZX62R-B-5P | http://www.mouser.dk/ProductDetail/Hirose-Electric/ZX62-B-5PA33/
J2 | CrazyFlie_EXP_HEADER | Left | 1 | CrazyFlieHeader
J3 | CrazyFlie_EXP_HEADER | Right | 1 | CrazyFlieHeader
L1 | SRN3015-220M | 22uH | 1 | 3.0mm x 3.0mm | http://www.mouser.dk/ProductDetail/Bourns/SRN3015-220M/
R3 | RES_0603 | 12k4 | 1 | RES_0603 | http://www.mouser.dk/ProductDetail/Vishay-Dale/CRCW060312K4FKEA/
R4 | RES_0603 | 91k | 1 | RES_0603 | http://www.mouser.dk/ProductDetail/Panasonic/ERJ-3EKF9102V/?qs=sGAEpiMZZMuvHVHkajiwYInseHxVa87A
R5, R6 | RES_0603 | 100k | 2 | RES_0603 | http://www.mouser.dk/ProductDetail/Panasonic/ERJ-3EKF1003V/?qs=sGAEpiMZZMtEZV4pKngjOTSI8dng3mTr
R19 | RES_0603 | 1k5 | 1 | RES_0603 | http://www.mouser.dk/ProductDetail/Vishay-Beyschlag/MCT06030C1501FP500/
S1, S2 | MC32882 | RESET, USER | 2 | KMR221G LFS | http://www.mouser.dk/ProductDetail/CK-Components/KMR221G-LFS/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
U2 | STM32F302CCT6 |  | 1 | LQFP48/7x7 | http://www.mouser.dk/ProductDetail/STMicroelectronics/STM32F302CCT6/
U4 | ISL85410 |  | 1 | L12.4x3 | http://www.mouser.dk/ProductDetail/Intersil/ISL85410FRZ/
U5 | DS28E05 |  | 1 | SOT23 | http://www.mouser.dk/ProductDetail/Maxim-Integrated/DS28E05R+T/?qs=sGAEpiMZZMu1UliJf38%252bvLCAtg%2f2iEl3
U9 | MPU9250 |  | 1 | QFN-24/3x3x1
Y1 | CFPX-5 |  | 1 | CFPX-5
Q1 | DMG2305UX |  | 1 | SOT23 | http://www.mouser.dk/ProductDetail/Diodes-Incorporated/DMG2305UX-7/
U3 | BCM857BS |  | 1 | SOT363 | http://www.mouser.dk/ProductDetail/NXP-Semiconductors/BCM857BS115/
D8 | SMBJ5.0A |  | 1 | DO-214AA | http://www.mouser.dk/ProductDetail/AVX/SMBJ50A/

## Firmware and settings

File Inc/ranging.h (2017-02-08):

#include "deca_device_api.h"
#include "deca_regs.h"
#include "decawave.h"
#include "hal.h"
#include "decaTime.h"
#include "device.h" 
#include "mac.h"
#include "deca.h"
#include "rng.h"


// messages used in the ranging protocol
#define POLL 0
#define POLL_ACK 1
#define RANGE 2
#define RANGE_REPORT 3
#define RANGE_FAILED 255
#define BLINK 4
#define RANGING_INIT 5
#define TOKEN_PASS 6
#define TOKEN_RETURN 7

#define MAX_DATA_LEN 90

//Max devices we put in the networkDevices array ! Each device is 74 Bytes in SRAM memory for now.
#define MAX_DEVICES 6


//Default value
//in ms
#define DEFAULT_RESET_PERIOD 600
//in us
#define DEFAULT_REPLY_DELAY_TIME 7000

//sketch type (anchor or tag)
#define TAG 0
#define ANCHOR 1

//default timer delay
#define DEFAULT_TIMER_DELAY 100



class rangingClass {
public:

	rangingClass();
	~rangingClass();

	//variables 
	// data buffer
	uint8_t data[MAX_DATA_LEN];
	
	
	//initialisation
	void    configureNetwork(uint16_t networkId, uint16_t ant_delay);
	void    startAsAnchor(uint8_t address[], uint16_t ant_delay);
	void    startAsTag(uint8_t address[], uint16_t ant_delay);
	bool	addNetworkDevices(device* dev, bool shortAddress);
	bool addNetworkDevices(device* dev);
	void    removeNetworkDevices(short index);
	
	//setters
	void setReplyTime(uint16_t replyDelayTimeUs);
	void setResetPeriod(unsigned long resetPeriod);
	
	//getters 
	uint8_t* getCurrentAddress() { return _currentAddress; };
	
	uint8_t* getCurrentShortAddress() { return _currentShortAddress; };
	
	short getNetworkDevicesNumber() { return _networkDevicesNumber; };
	device* getNetworkDevice(int index);
	
	//ranging functions
	short detectMessageType(uint8_t datas[]);
	void  loop();
	
	
	//Handlers:
	void attachNewDevice(void (* handleNewDevice)(device* distantDevice)) { _handleNewDevice = handleNewDevice; };
	void attachRemovedDevice(void (* handleRemovedDevice)(device* distantDevice)) { _handleRemovedDevice = handleRemovedDevice; };
	void attachNewRange(void (* handleNewRange)(device* distantDevices, short networkDevices)) { _handleNewRange = handleNewRange; };
	void attachNewAnchorRange(void (* handleNewAnchorRange)(float * ranges)) { _handleNewAnchorRange = handleNewAnchorRange; };
	
	
	device* getDistantDevice();
	device* searchDistantDevice(uint8_t shortAddress[]);

	static void handleSent(const dwt_callback_data_t * data);
	static void handleReceived(const dwt_callback_data_t * data);
	
	//FOR DEBUGGING
	//void visualizeDatas(uint8_t datas[]);


private:
	//other devices in the network
	device _networkDevices[MAX_DEVICES];
	short        _networkDevicesNumber;
	short        _lastDistantDevice;
	uint8_t         _currentAddress[8];
	uint8_t         _currentShortAddress[2];
	uint8_t         _lastSentToShortAddress[2];
	mac    _globalMac;
	long         timer;
	short        counterForBlink;
	static const dwt_callback_data_t * _sentCallbackData;
	static const dwt_callback_data_t * _receivedCallbackData;
	decaTime _tx_ant_delay;

	device trueMaster;
	bool tokenHolder = false;
	bool newTokenHolder = false;
	bool trueTag = false;
	short tokenCounter = 0;

	
	//Handlers:
	void (* _handleNewDevice)(device* distantDevice);
	void (* _handleRemovedDevice)(device* distantDevice);
	void (* _handleNewRange)(device* distantDevices, short networkDevices);
	void (* _handleNewAnchorRange)(float * ranges);
	
	//sketch type (tag or anchor)
	short              _type; //0 for tag and 1 for anchor
	// message flow state
	volatile uint8_t    _expectedMsgId;
	// message sent/received state
	static volatile bool _sentAck;
	static volatile bool _receivedAck;
	// protocol error state
	bool          _protocolFailed;
	// watchdog and reset period
	unsigned long    _lastActivity;
	unsigned long    _resetPeriod;
	// reply times (same on both sides for symm. ranging)
	uint16_t     _replyDelayTimeUS;
	//timer Tick delay
	long     _timerDelay;
	// ranging counter (per second)
	//unsigned int     _successRangingCount;
	//unsigned long    _rangingCountPeriod;
		
	
	//methods
	
	void noteActivity();
	void resetInactive();
	
	//global functions:
	void checkForReset();
	void checkForInactiveDevices();
	void copyShortAddress(uint8_t address1[], uint8_t address2[]);
	
	//for ranging protocole (ANCHOR)
	void transmit(uint8_t datas[], uint8_t len);
	void transmitNow(uint8_t datas[], uint8_t len);
	void transmit(uint8_t datas[], decaTime deltatime, uint8_t len);
	void transmitBlink();
	void transmitRangingInit(device* myDistantDevice);
	void transmitPollAck(device* myDistantDevice);
	void transmitRangeReport(device* myDistantDevice);
	void transmitRangeFailed(device* myDistantDevice);
	void transmitToken(device* myDistantDevice);
	void transmitReturnToken(device* myDistantDevice);
	
	//for ranging protocole (TAG)
	void transmitPoll(device* myDistantDevice);
	void transmitRange(device* myDistantDevice);
	
	//methods for range computation
	void computeRangeAsymmetric(device* myDistantDevice, decaTime* myTOF);
	
	void timerTick();
	
};

//extern rangingClass ranging;

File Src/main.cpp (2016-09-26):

/**
  ******************************************************************************
  * File Name          : main.c
  * Description        : Main program body
  ******************************************************************************
  *
  * COPYRIGHT(c) 2016 STMicroelectronics
  *
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
  ******************************************************************************
  */
/* Includes ------------------------------------------------------------------*/
#include <string.h>
#include <stdio.h>
#include <stdint.h>
#include <stdbool.h>
#include "hal.h"
#include "sys.h"
#include "i2c.h"
#include "spi.h"
#include "tim.h"
#include "dma.h"
#include "gpio.h"
#include "log.h"
#include "led.h"
#include "usb_device.h"
#include "decawave.h"
#include "deca_device_api.h"
#include "deca_regs.h"

#include "deca.h"
#include "mac.h"
#include "ranging.h"
#include "decaTime.h"
#include "packet.h"

/* USER CODE BEGIN PV */

#define N_NODES 9
// {CPU_ID0, TYPE, ANT_DLY}
unsigned int boards[N_NODES][3] = {
  {0x87153806, ANCHOR, DEFAULT_ANT_DLY},
  {0x003a003a, ANCHOR, 32910},
  {0x00220039, ANCHOR, 32910},
  {0x001e0039, ANCHOR, 32889},
  {0x00300039, ANCHOR, 32923},
  {0x87153929, ANCHOR, DEFAULT_ANT_DLY},
  {0x0032003e, TAG,    DEFAULT_ANT_DLY},   
  {0xffffffff, ANCHOR, DEFAULT_ANT_DLY},
  {0xffffffff, ANCHOR, DEFAULT_ANT_DLY},
};

rangingClass ranging;

/* USER CODE END PV */

void SystemClock_Config(void);
void Error_Handler(void);

/* USER CODE BEGIN PFP */

/* USER CODE END PFP */

int main(void)
{

  /* MCU Configuration----------------------------------------------------------*/

  /* Reset of all peripherals, Initializes the Flash interface and the Systick. */
  HAL_Init();

  /* Configure the system clock */
  SystemClock_Config();

  /* Initialize all configured peripherals */
  MX_GPIO_Init();
  MX_LED_Init();
  MX_DMA_Init();
  MX_TIM1_Init();
  MX_USB_DEVICE_Init();
  MX_IMU_I2C_Init();
  MX_DECA_SPI_Init();
  MX_CLIENT_SPI_Init();

  /* USER CODE BEGIN 2 */
  HAL_Delay(2000);

  LED_On(LED_1);

  int boardId = 0;

  // Finding the boad ID
  for(int i=0; i<N_NODES; i++){
    if(STM32_UUID[0] == boards[i][0]){
      boardId = i+1;
    }
  }


  uint32_t devID = dwt_readdevid() ;
  MPL_LOGD("Device ID: 0x%08x (%s)\n", (unsigned int)devID, devID==0xdeca0130?"OK":"ERROR");

  if(boardId == 0){
    while(1){
      MPL_LOGE("CPUID: 0x%08x (Board ID: %s)\n", (unsigned int)STM32_UUID[0], "UNKNOWN");
      HAL_Delay(1000);
    }
  }else{
    MPL_LOGD("CPUID: 0x%08x (Board ID: %02d)\n", (unsigned int)STM32_UUID[0], boardId);
  }

  /* USER CODE END 2 */

  /* Infinite loop */
  /* USER CODE BEGIN WHILE */

  uint8_t address[8];
  uint8_t cnt = 0;
  for(int i=0; i < 3; i++){
    for(int j=0; j < 4; j++){
      address[cnt++] = (uint8_t)(STM32_UUID[i] >> (j*8));
    }
  }
  


  if(boards[boardId-1][1] == ANCHOR){
    ranging.startAsAnchor(address, boards[boardId-1][2]);
  }else{
    ranging.startAsTag(address, boards[boardId-1][2]);
  }


  while(1){

    /*if (USART_GetITStatus(USARTx, USART_IT_RXNE)) {
        USART_ClearITPendingBit(USARTx, USART_IT_RXNE);
        //handle_input();
    }*/

    ranging.loop();
  }
  /* USER CODE END 3 */

}

/**
  * @}
  */ 

/**
  * @}
*/ 

/************************ (C) COPYRIGHT STMicroelectronics *****END OF FILE****/

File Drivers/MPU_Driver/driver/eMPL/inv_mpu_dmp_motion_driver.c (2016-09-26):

/*
 $License:
    Copyright (C) 2011-2012 InvenSense Corporation, All Rights Reserved.
    See included License.txt for License information.
 $
 */
/**
 *  @addtogroup  DRIVERS Sensor Driver Layer
 *  @brief       Hardware drivers to communicate with sensors via I2C.
 *
 *  @{
 *      @file       inv_mpu_dmp_motion_driver.c
 *      @brief      DMP image and interface functions.
 *      @details    All functions are preceded by the dmp_ prefix to
 *                  differentiate among MPL and general driver function calls.
 */
#include <stdio.h>
#include <stdint.h>
#include <stdlib.h>
#include <string.h>
#include <math.h>
#include "inv_mpu.h"
#include "inv_mpu_dmp_motion_driver.h"
#include "dmpKey.h"
#include "dmpmap.h"
#include "port.h"

/* The following functions must be defined for this platform:
 * i2c_write(unsigned char slave_addr, unsigned char reg_addr,
 *      unsigned char length, unsigned char const *data)
 * i2c_read(unsigned char slave_addr, unsigned char reg_addr,
 *      unsigned char length, unsigned char *data)
 * delay_ms(unsigned long num_ms)
 * get_ms(unsigned long *count)
 */
#if defined EMPL_TARGET_STM32F1xx
#include "mpu_i2c.h"   
#include "log.h"   
   
#define i2c_write   Sensors_I2C_WriteRegister
#define i2c_read    Sensors_I2C_ReadRegister
#define get_ms      ms_cnt
#define delay_ms    Delay
#define log_i       MPL_LOGI
#define log_e       MPL_LOGE

#else
#error  Gyro driver is missing the system layer implementations.
#endif

/* These defines are copied from dmpDefaultMPU6050.c in the general MPL
 * releases. These defines may change for each DMP image, so be sure to modify
 * these values when switching to a new image.
 */
#define CFG_LP_QUAT             (2712)
#define END_ORIENT_TEMP         (1866)
#define CFG_27                  (2742)
#define CFG_20                  (2224)
#define CFG_23                  (2745)
#define CFG_FIFO_ON_EVENT       (2690)
#define END_PREDICTION_UPDATE   (1761)
#define CGNOTICE_INTR           (2620)
#define X_GRT_Y_TMP             (1358)
#define CFG_DR_INT              (1029)
#define CFG_AUTH                (1035)
#define UPDATE_PROP_ROT         (1835)
#define END_COMPARE_Y_X_TMP2    (1455)
#define SKIP_X_GRT_Y_TMP        (1359)
#define SKIP_END_COMPARE        (1435)
#define FCFG_3                  (1088)
#define FCFG_2                  (1066)
#define FCFG_1                  (1062)
#define END_COMPARE_Y_X_TMP3    (1434)
#define FCFG_7                  (1073)
#define FCFG_6                  (1106)
#define FLAT_STATE_END          (1713)
#define SWING_END_4             (1616)
#define SWING_END_2             (1565)
#define SWING_END_3             (1587)
#define SWING_END_1             (1550)
#define CFG_8                   (2718)
#define CFG_15                  (2727)
#define CFG_16                  (2746)
#define CFG_EXT_GYRO_BIAS       (1189)
#define END_COMPARE_Y_X_TMP     (1407)
#define DO_NOT_UPDATE_PROP_ROT  (1839)
#define CFG_7                   (1205)
#define FLAT_STATE_END_TEMP     (1683)
#define END_COMPARE_Y_X         (1484)
#define SKIP_SWING_END_1        (1551)
#define SKIP_SWING_END_3        (1588)
#define SKIP_SWING_END_2        (1566)
#define TILTG75_START           (1672)
#define CFG_6                   (2753)
#define TILTL75_END             (1669)
#define END_ORIENT              (1884)
#define CFG_FLICK_IN            (2573)
#define TILTL75_START           (1643)
#define CFG_MOTION_BIAS         (1208)
#define X_GRT_Y                 (1408)
#define TEMPLABEL               (2324)
#define CFG_ANDROID_ORIENT_INT  (1853)
#define CFG_GYRO_RAW_DATA       (2722)
#define X_GRT_Y_TMP2            (1379)

#define D_0_22                  (22+512)
#define D_0_24                  (24+512)

#define D_0_36                  (36)
#define D_0_52                  (52)
#define D_0_96                  (96)
#define D_0_104                 (104)
#define D_0_108                 (108)
#define D_0_163                 (163)
#define D_0_188                 (188)
#define D_0_192                 (192)
#define D_0_224                 (224)
#define D_0_228                 (228)
#define D_0_232                 (232)
#define D_0_236                 (236)

#define D_1_2                   (256 + 2)
#define D_1_4                   (256 + 4)
#define D_1_8                   (256 + 8)
#define D_1_10                  (256 + 10)
#define D_1_24                  (256 + 24)
#define D_1_28                  (256 + 28)
#define D_1_36                  (256 + 36)
#define D_1_40                  (256 + 40)
#define D_1_44                  (256 + 44)
#define D_1_72                  (256 + 72)
#define D_1_74                  (256 + 74)
#define D_1_79                  (256 + 79)
#define D_1_88                  (256 + 88)
#define D_1_90                  (256 + 90)
#define D_1_92                  (256 + 92)
#define D_1_96                  (256 + 96)
#define D_1_98                  (256 + 98)
#define D_1_106                 (256 + 106)
#define D_1_108                 (256 + 108)
#define D_1_112                 (256 + 112)
#define D_1_128                 (256 + 144)
#define D_1_152                 (256 + 12)
#define D_1_160                 (256 + 160)
#define D_1_176                 (256 + 176)
#define D_1_178                 (256 + 178)
#define D_1_218                 (256 + 218)
#define D_1_232                 (256 + 232)
#define D_1_236                 (256 + 236)
#define D_1_240                 (256 + 240)
#define D_1_244                 (256 + 244)
#define D_1_250                 (256 + 250)
#define D_1_252                 (256 + 252)
#define D_2_12                  (512 + 12)
#define D_2_96                  (512 + 96)
#define D_2_108                 (512 + 108)
#define D_2_208                 (512 + 208)
#define D_2_224                 (512 + 224)
#define D_2_236                 (512 + 236)
#define D_2_244                 (512 + 244)
#define D_2_248                 (512 + 248)
#define D_2_252                 (512 + 252)

#define CPASS_BIAS_X            (35 * 16 + 4)
#define CPASS_BIAS_Y            (35 * 16 + 8)
#define CPASS_BIAS_Z            (35 * 16 + 12)
#define CPASS_MTX_00            (36 * 16)
#define CPASS_MTX_01            (36 * 16 + 4)
#define CPASS_MTX_02            (36 * 16 + 8)
#define CPASS_MTX_10            (36 * 16 + 12)
#define CPASS_MTX_11            (37 * 16)
#define CPASS_MTX_12            (37 * 16 + 4)
#define CPASS_MTX_20            (37 * 16 + 8)
#define CPASS_MTX_21            (37 * 16 + 12)
#define CPASS_MTX_22            (43 * 16 + 12)
#define D_EXT_GYRO_BIAS_X       (61 * 16)
#define D_EXT_GYRO_BIAS_Y       (61 * 16) + 4
#define D_EXT_GYRO_BIAS_Z       (61 * 16) + 8
#define D_ACT0                  (40 * 16)
#define D_ACSX                  (40 * 16 + 4)
#define D_ACSY                  (40 * 16 + 8)
#define D_ACSZ                  (40 * 16 + 12)
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
